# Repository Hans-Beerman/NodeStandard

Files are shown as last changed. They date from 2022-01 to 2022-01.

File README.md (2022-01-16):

**NodeStandard**

NodeStandard is the base for different nodes, used at the MakerSpace Leiden, to control different pieces of equipment. This repository has the following subdirs:

- **Drawings:**

- **Gerber_Files:**

This directory contains the Gerber files for production of the print. In this directory are the separate files and a *.ZIP file containing all these files. For ordering the printed circuit board, for example from JLCPCB, you only need to upload the ZIP file

Schematic of the wiring between the different modules used

- **KiCad\_files:**

The design of the PCB for the Node/Controller. De PCB in this design is not meant to be used for a real PCB. It is used as guideline for a handmade PCB

- **Photos:**

Some photos of the Node made.

- **PlatformIO\_Files:**

The source code for the Node and the display used. For the development of this software PlatformIO is used. PlatformIO is an Extension on Visual Studio Code.

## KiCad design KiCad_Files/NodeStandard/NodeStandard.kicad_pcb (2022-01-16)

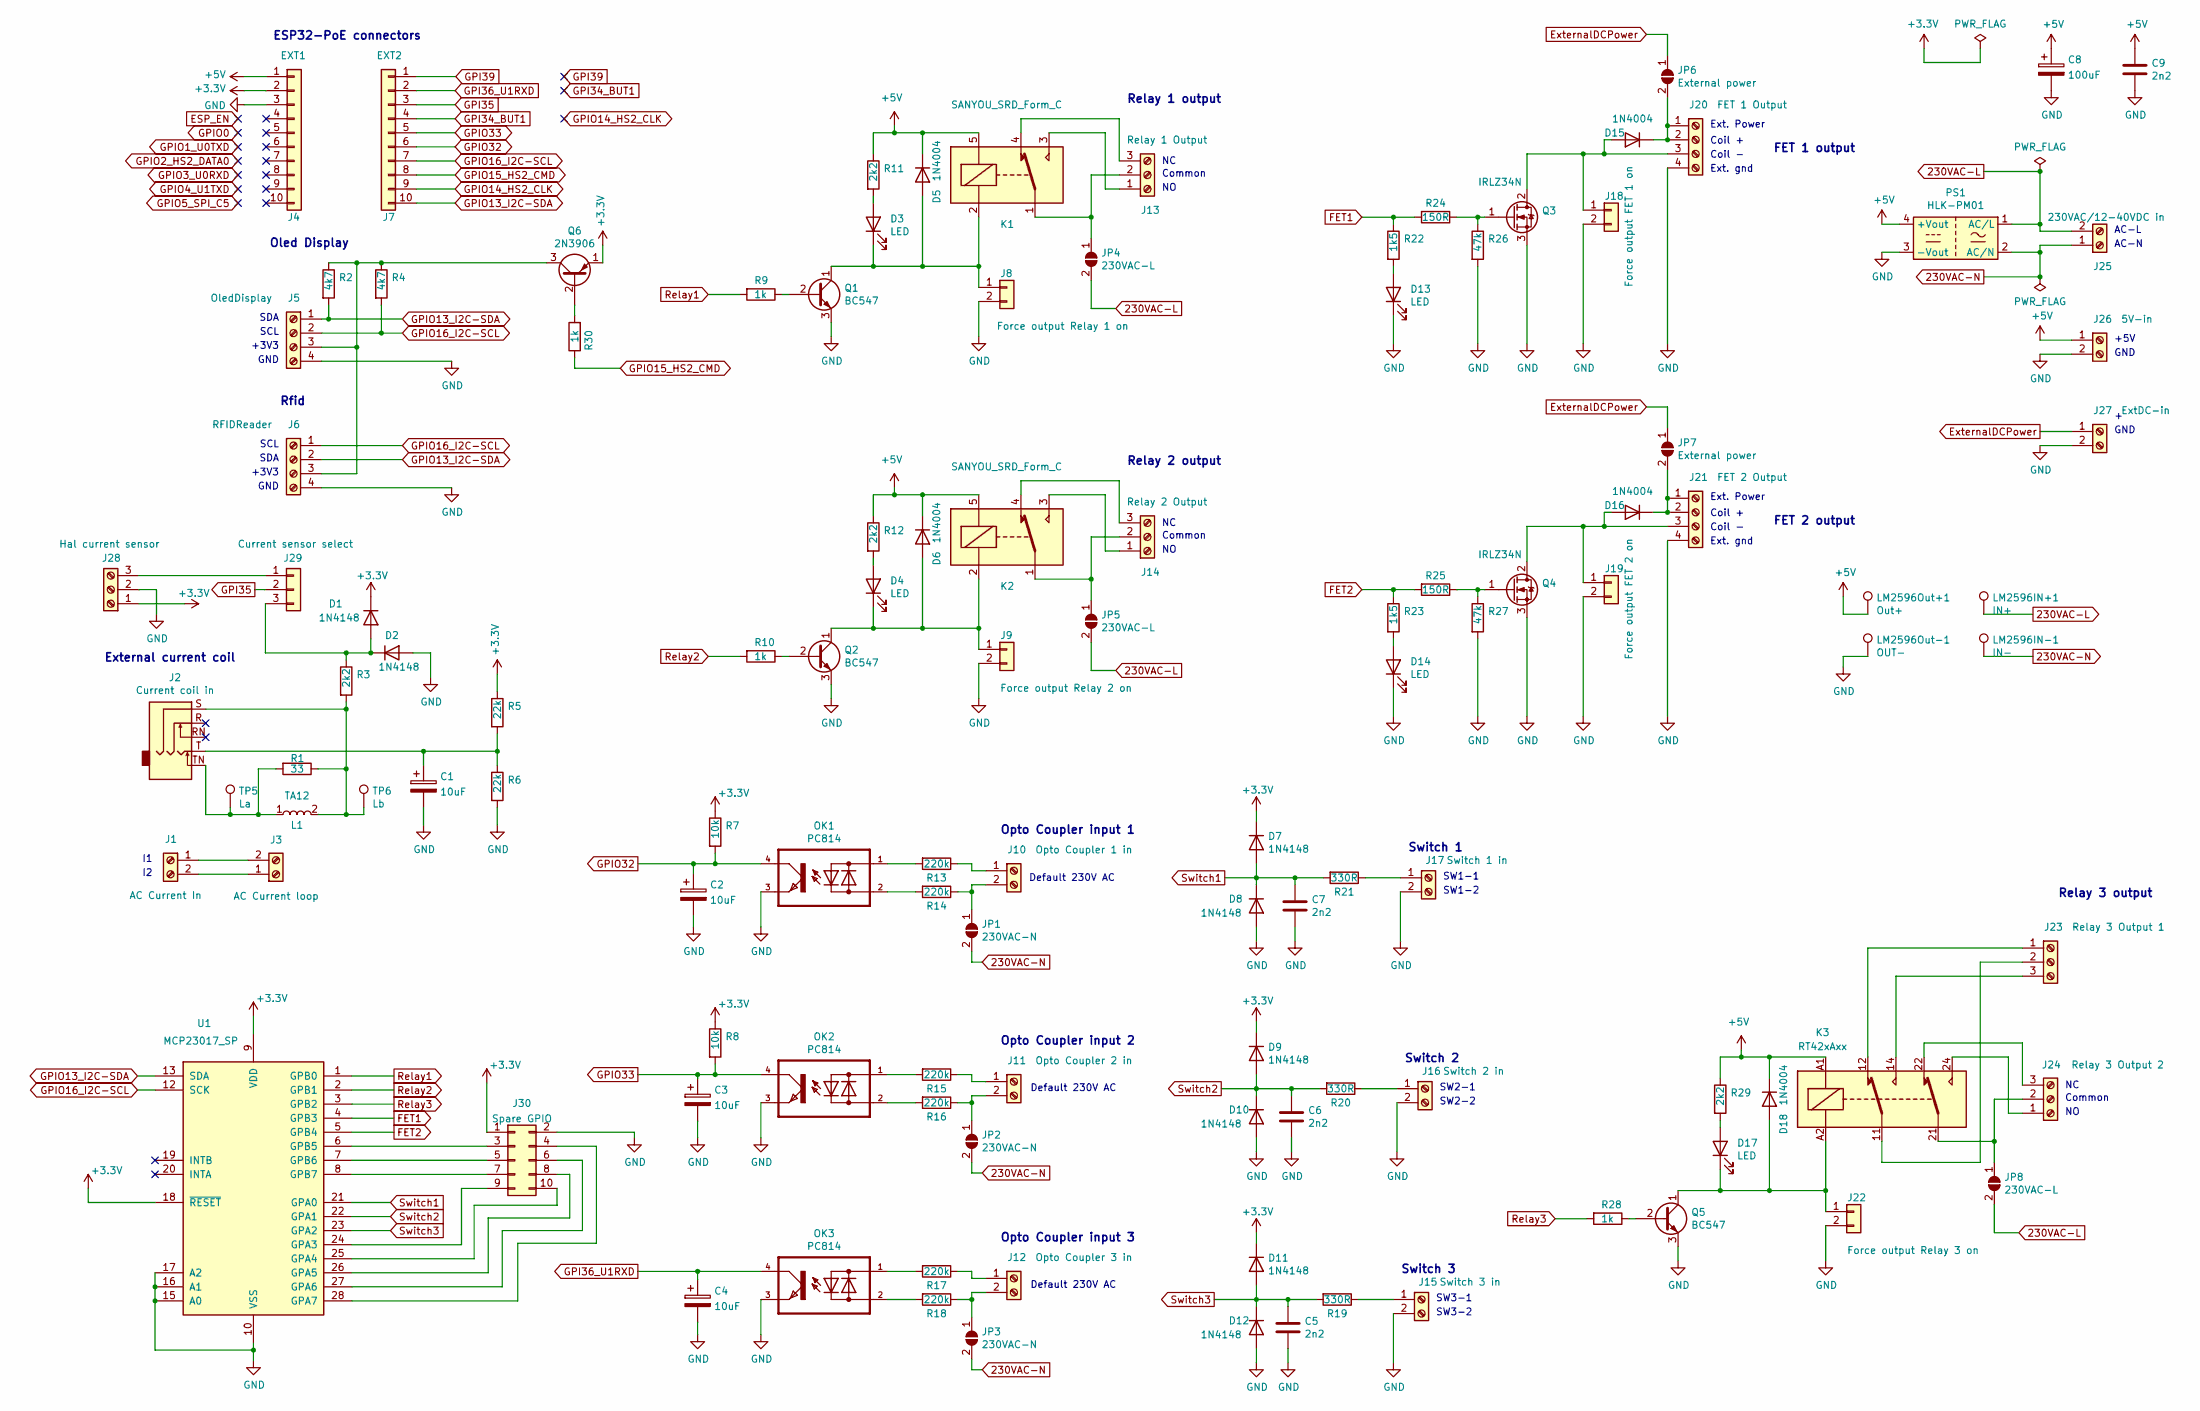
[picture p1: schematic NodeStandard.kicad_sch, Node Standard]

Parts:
C1, C2, C3, C4: 10uF; CP_Radial_D6.3mm_P2.50mm
C5, C6, C7, C9: 2n2; C_Disc_D5.1mm_W3.2mm_P5.00mm
C8: 100uF; CP_Radial_D6.3mm_P2.50mm
D1, D2, D7, D8, D9, D10, D11, D12: 1N4148; D_DO-35_SOD27_P7.62mm_Horizontal
D3, D4, D13, D14, D17: LED; LED_D3.0mm
D5, D6, D15, D16, D18: 1N4004; D_DO-41_SOD81_P10.16mm_Horizontal
J1: AC Current In; PhoenixContact_MSTB_2,5_2-GF-5,08_1x02_P5.08mm_Horizontal_T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
J2: Current coil in; Jack_3.5mm_CUI_FEMPM_Horizontal
J3: AC Current loop; TerminalBlock_Phoenix_MKDS-1,5-2-5.08_1x02_P5.08mm_Horizont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
J4: EXT1; PinSocket_1x10_P2.54mm_Vertical
J5: OledDisplay; TerminalBlock_Phoenix_MPT-0,5-4-2.54_1x04_P2.54mm_Horizontal
J6: RFIDReader; TerminalBlock_Phoenix_MPT-0,5-4-2.54_1x04_P2.54mm_Horizontal
J7: EXT2; PinSocket_1x10_P2.54mm_Vertical
J8: Force output Relay 1 on; PinHeader_1x02_P2.54mm_Vertical
J9: Force output Relay 2 on; PinHeader_1x02_P2.54mm_Vertical
J10: Opto Coupler 1 in; PhoenixContact_MSTB_2,5_2-GF-5,08_1x02_P5.08mm_Horizontal_T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
J11: Opto Coupler 2 in; PhoenixContact_MSTB_2,5_2-GF-5,08_1x02_P5.08mm_Horizontal_T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
J12: Opto Coupler 3 in; PhoenixContact_MSTB_2,5_2-GF-5,08_1x02_P5.08mm_Horizontal_T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
J13: Relay 1 Output; PhoenixContact_MSTB_2,5_3-GF-5,08_1x03_P5.08mm_Horizontal_T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
J14: Relay 2 Output; PhoenixContact_MSTB_2,5_3-GF-5,08_1x03_P5.08mm_Horizontal_T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
J15: Switch 3 in; TerminalBlock_Phoenix_MPT-0,5-2-2.54_1x02_P2.54mm_Horizontal
J16: Switch 2 in; TerminalBlock_Phoenix_MPT-0,5-2-2.54_1x02_P2.54mm_Horizontal
J17: Switch 1 in; TerminalBlock_Phoenix_MPT-0,5-2-2.54_1x02_P2.54mm_Horizontal
J18: Force output FET 1 on; PinHeader_1x02_P2.54mm_Vertical
J19: Force output FET 2 on; PinHeader_1x02_P2.54mm_Vertical
J20: FET 1 Output; PhoenixContact_MSTB_2,5_4-GF-5,08_1x04_P5.08mm_Horizontal_T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
J21: FET 2 Output; PhoenixContact_MSTB_2,5_4-GF-5,08_1x04_P5.08mm_Horizontal_T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
J22: Force output Relay 3 on; PinHeader_1x02_P2.54mm_Vertical
J23: Relay 3 Output 1; PhoenixContact_MSTB_2,5_3-GF-5,08_1x03_P5.08mm_Horizontal_T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
J24: Relay 3 Output 2; PhoenixContact_MSTB_2,5_3-GF-5,08_1x03_P5.08mm_Horizontal_T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
J25: 230VAC/12-40VDC in; PhoenixContact_MSTB_2,5_2-GF-5,08_1x02_P5.08mm_Horizontal_T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
J26: 5V-in; PhoenixContact_MSTB_2,5_2-GF-5,08_1x02_P5.08mm_Horizontal_T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
J27: ExtDC-in; PhoenixContact_MSTB_2,5_2-GF-5,08_1x02_P5.08mm_Horizontal_T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
J28: Hal current sensor; TerminalBlock_Phoenix_MPT-0,5-3-2.54_1x03_P2.54mm_Horizontal
J29: Current sensor select; PinHeader_1x03_P2.54mm_Vertical
J30: Spare GPIO; PinHeader_2x05_P2.54mm_Vertical
JP1, JP2, JP3: 230VAC-N; SolderJumper-2_P3mm_Open_RoundedPad
JP4, JP5, JP8: 230VAC-L; SolderJumper-2_P3mm_Open_RoundedPad
JP6, JP7: External power; SolderJumper-2_P1.3mm_Open_RoundedPad1.0x1.5mm
K1, K2: SANYOU_SRD_Form_C; Relay_SPDT_SANYOU_SRD_Series_Form_C
K3: RT42xAxx; Relay_DPDT_Schrack-RT2-FormC_RM5mm
L1: TA12; TA12-100
LM2596IN+1: IN+; TestPoint_THTPad_2.0x2.0mm_Drill1.0mm
LM2596IN-1: IN-; TestPoint_THTPad_2.0x2.0mm_Drill1.0mm
LM2596Out+1: Out+; TestPoint_THTPad_2.0x2.0mm_Drill1.0mm
LM2596Out-1: OUT-; TestPoint_THTPad_2.0x2.0mm_Drill1.0mm
OK1, OK2, OK3: PC814; DIP-4_W7.62mm
PS1: HLK-PM01; Converter_ACDC_HiLink_HLK-PMxx
Q1, Q2, Q5: BC547; TO-92_Inline
Q3, Q4: IRLZ34N; TO-220-3_Vertical
Q6: 2N3906; TO-92_Inline
R1: 33; R_Axial_DIN0207_L6.3mm_D2.5mm_P7.62mm_Horizontal
R2, R4: 4k7; R_Axial_DIN0207_L6.3mm_D2.5mm_P7.62mm_Horizontal
R3, R11, R12, R29: 2k2; R_Axial_DIN0207_L6.3mm_D2.5mm_P7.62mm_Horizontal
R5, R6: 22k; R_Axial_DIN0207_L6.3mm_D2.5mm_P7.62mm_Horizontal
R7, R8: 10k; R_Axial_DIN0207_L6.3mm_D2.5mm_P7.62mm_Horizontal
R9, R10, R28, R30: 1k; R_Axial_DIN0207_L6.3mm_D2.5mm_P7.62mm_Horizontal
R13, R14, R15, R16, R17, R18: 220k; R_Axial_DIN0516_L15.5mm_D5.0mm_P20.32mm_Horizontal
R19, R20, R21: 330R; R_Axial_DIN0207_L6.3mm_D2.5mm_P7.62mm_Horizontal
R22, R23: 1k5; R_Axial_DIN0207_L6.3mm_D2.5mm_P7.62mm_Horizontal
R24, R25: 150R; R_Axial_DIN0207_L6.3mm_D2.5mm_P7.62mm_Horizontal
R26, R27: 47k; R_Axial_DIN0207_L6.3mm_D2.5mm_P7.62mm_Horizontal
TP5: La; TestPoint_THTPad_2.5x2.5mm_Drill1.2mm
TP6: Lb; TestPoint_THTPad_2.5x2.5mm_Drill1.2mm
U1: MCP23017_SP; DIP-28_W7.62mm

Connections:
230VAC-L: J25.2, JP4.2 (B), JP5.2 (B), JP8.2 (B), LM2596IN+1.1, PS1.1 (AC/L)
230VAC-N: J25.1, JP1.2 (B), JP2.2 (B), JP3.2 (B), LM2596IN-1.1, PS1.2 (AC/N)
+3V3: D1.1 (K), D7.1 (K), D9.1 (K), D11.1 (K), J4.2, J28.1, J30.1, Q6.1 (E), R5.1, R7.1, R8.1, U1.9 (VDD), U1.18 (~RESET)
+5V: C8.1, C9.1, D5.1 (K), D6.1 (K), D18.1 (K), J4.1, J26.1, K1.5, K2.5, K3.A1, LM2596Out+1.1, PS1.4 (+Vout), R11.1, R12.1, R29.1
ExternalDCPower: J27.1, JP6.1 (A), JP7.1 (A)
FET1: R22.1, R24.2, U1.4 (GPB3)
FET2: R23.1, R25.2, U1.5 (GPB4)
GND: C1.2, C2.2, C3.2, C4.2, C5.2, C6.2, C7.2, C8.2, C9.2, D2.2 (A), D8.2 (A), D10.2 (A), D12.2 (A), D13.1 (K), D14.1 (K), J4.3, J5.4, J6.4, J8.2, J9.2, J15.2, J16.2, J17.2, J18.2, J19.2, J20.4, J21.4, J22.2, J26.2, J27.2, J28.2, J30.2, LM2596Out-1.1, OK1.3 (E), OK2.3 (E), OK3.3 (E), PS1.3 (-Vout), Q1.3 (E), Q2.3 (E), Q3.3 (S), Q4.3 (S), Q5.3 (E), R6.2, R26.2, R27.2, U1.10 (VSS), U1.15 (A0), U1.16 (A1), U1.17 (A2)
GPI34_BUT1: J7.4
GPI35: J7.3, J29.2
GPI36_U1RXD: C4.1, J7.2, OK3.4 (C)
GPI39: J7.1
GPIO13_I2C-SDA: J5.1, J6.2, J7.10, R2.2, U1.13 (SDA)
GPIO14_HS2_CLK: J7.9
GPIO15_HS2_CMD: J7.8, R30.1
GPIO16_I2C-SCL: J5.2, J6.1, J7.7, R4.2, U1.12 (SCK)
GPIO32: C2.1, J7.6, OK1.4 (C), R7.2
GPIO33: C3.1, J7.5, OK2.4 (C), R8.2
unnamed: C1.1, J2.T, R5.2, R6.1
unnamed: D1.2 (A), D2.1 (K), J29.3, R3.1
unnamed: D3.1 (K), D5.2 (A), J8.1, K1.2, Q1.1 (C)
unnamed: D3.2 (A), R11.2
unnamed: D4.1 (K), D6.2 (A), J9.1, K2.2, Q2.1 (C)
unnamed: D4.2 (A), R12.2
unnamed: D13.2 (A), R22.2
unnamed: D14.2 (A), R23.2
unnamed: D15.1 (K), J20.1, J20.2, JP6.2 (B)
unnamed: D15.2 (A), J18.1, J20.3, Q3.2 (D)
unnamed: D16.1 (K), J21.1, J21.2, JP7.2 (B)
unnamed: D16.2 (A), J19.1, J21.3, Q4.2 (D)
unnamed: D17.1 (K), D18.2 (A), J22.1, K3.A2, Q5.1 (C)
unnamed: D17.2 (A), R29.2
unnamed: J1.1, J3.2
unnamed: J1.2, J3.1
unnamed: J2.S, L1.2, R1.1, R3.2, TP6.1
unnamed: J2.TN, L1.1, R1.2, TP5.1
unnamed: J5.3, J6.3, Q6.3 (C), R2.1, R4.1
unnamed: J10.1, R13.1
unnamed: J10.2, JP1.1 (A), R14.1
unnamed: J11.1, R15.1
unnamed: J11.2, JP2.1 (A), R16.1
unnamed: J12.1, R17.1
unnamed: J12.2, JP3.1 (A), R18.1
unnamed: J13.1, K1.3
unnamed: J13.2, JP4.1 (A), K1.1
unnamed: J13.3, K1.4
unnamed: J14.1, K2.3
unnamed: J14.2, JP5.1 (A), K2.1
unnamed: J14.3, K2.4
unnamed: J15.1, R19.1
unnamed: J16.1, R20.1
unnamed: J17.1, R21.1
unnamed: J23.1, K3.12
unnamed: J23.2, K3.11
unnamed: J23.3, K3.14
unnamed: J24.1, K3.24
unnamed: J24.2, JP8.1 (A), K3.21
unnamed: J24.3, K3.22
unnamed: J28.3, J29.1
unnamed: J30.3, U1.6 (GPB5)
unnamed: J30.4, U1.28 (GPA7)
unnamed: J30.5, U1.7 (GPB6)
unnamed: J30.6, U1.27 (GPA6)
unnamed: J30.7, U1.8 (GPB7)
unnamed: J30.8, U1.26 (GPA5)
unnamed: J30.9, U1.24 (GPA3)
unnamed: J30.10, U1.25 (GPA4)
unnamed: OK1.1 (AC1), R13.2
unnamed: OK1.2 (AC2), R14.2
unnamed: OK2.1 (AC1), R15.2
unnamed: OK2.2 (AC2), R16.2
unnamed: OK3.1 (AC1), R17.2
unnamed: OK3.2 (AC2), R18.2
unnamed: Q1.2 (B), R9.1
unnamed: Q2.2 (B), R10.1
unnamed: Q3.1 (G), R24.1, R26.1
unnamed: Q4.1 (G), R25.1, R27.1
unnamed: Q5.2 (B), R28.1
unnamed: Q6.2 (B), R30.2
Relay1: R9.2, U1.1 (GPB0)
Relay2: R10.2, U1.2 (GPB1)
Relay3: R28.2, U1.3 (GPB2)
Switch1: C7.1, D7.2 (A), D8.1 (K), R21.2, U1.21 (GPA0)
Switch2: C6.1, D9.2 (A), D10.1 (K), R20.2, U1.22 (GPA1)
Switch3: C5.1, D11.2 (A), D12.1 (K), R19.2, U1.23 (GPA2)

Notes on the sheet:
SDA
GND
+3V3
Ext. gnd
SW3-2
Switch 3
+5V
Rfid
SCL
SW2-1
ESP32-PoE connectors
Common
AC-L
Default 230V AC
Ext. Power
Coil +
Switch 2
Relay 2 output
SW2-2
External current coil
SW1-1
Coil -
Switch 1
SW1-2
Relay 3 output
FET 1 output
Oled Display
Opto Coupler input 2
Opto Coupler input 1
AC-N
Relay 1 output
Opto Coupler input 3
FET 2 output
SW3-1

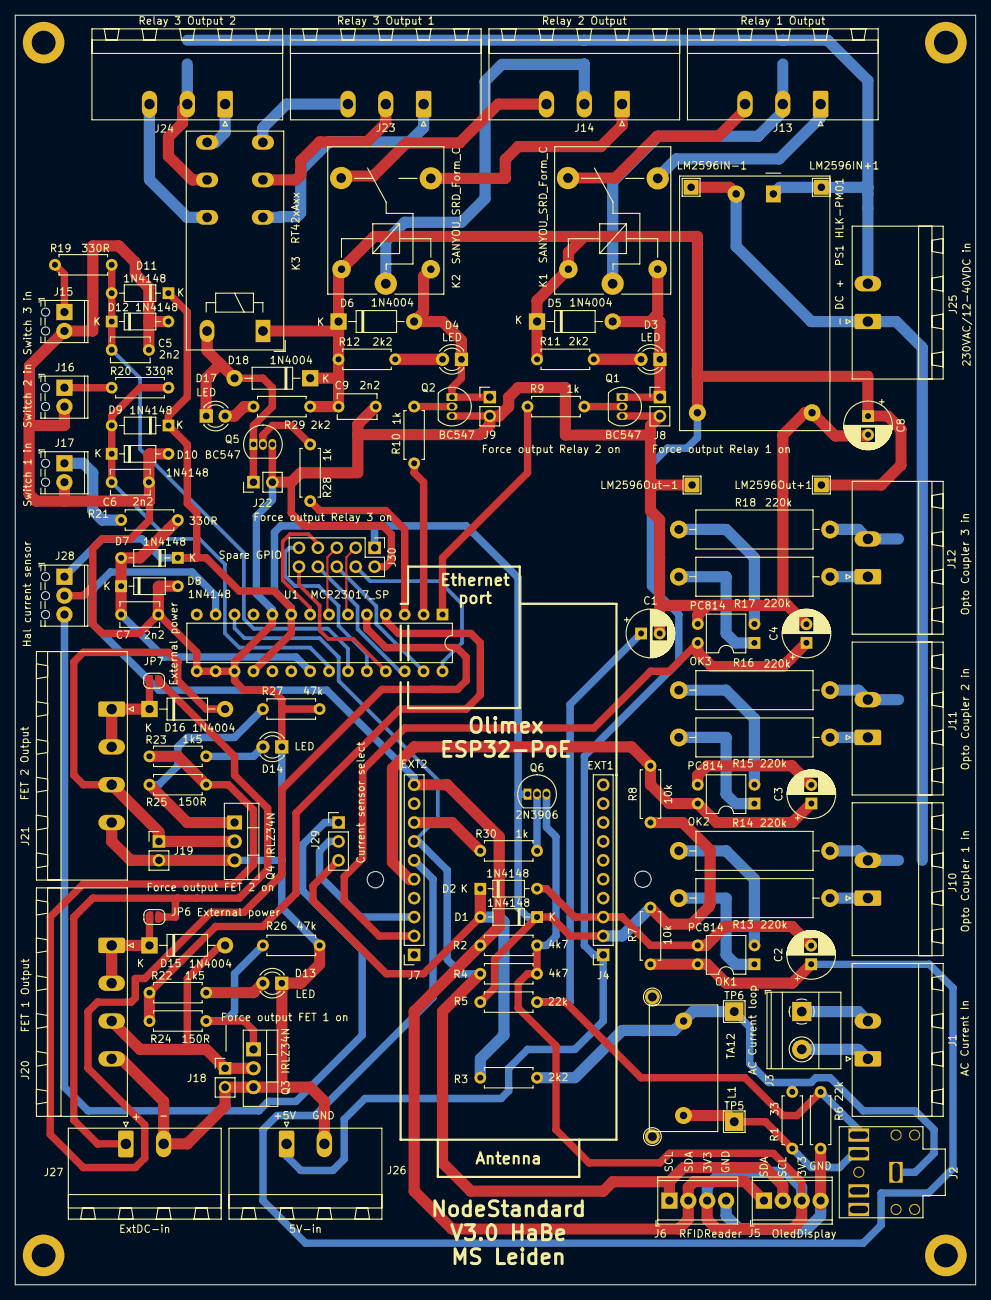
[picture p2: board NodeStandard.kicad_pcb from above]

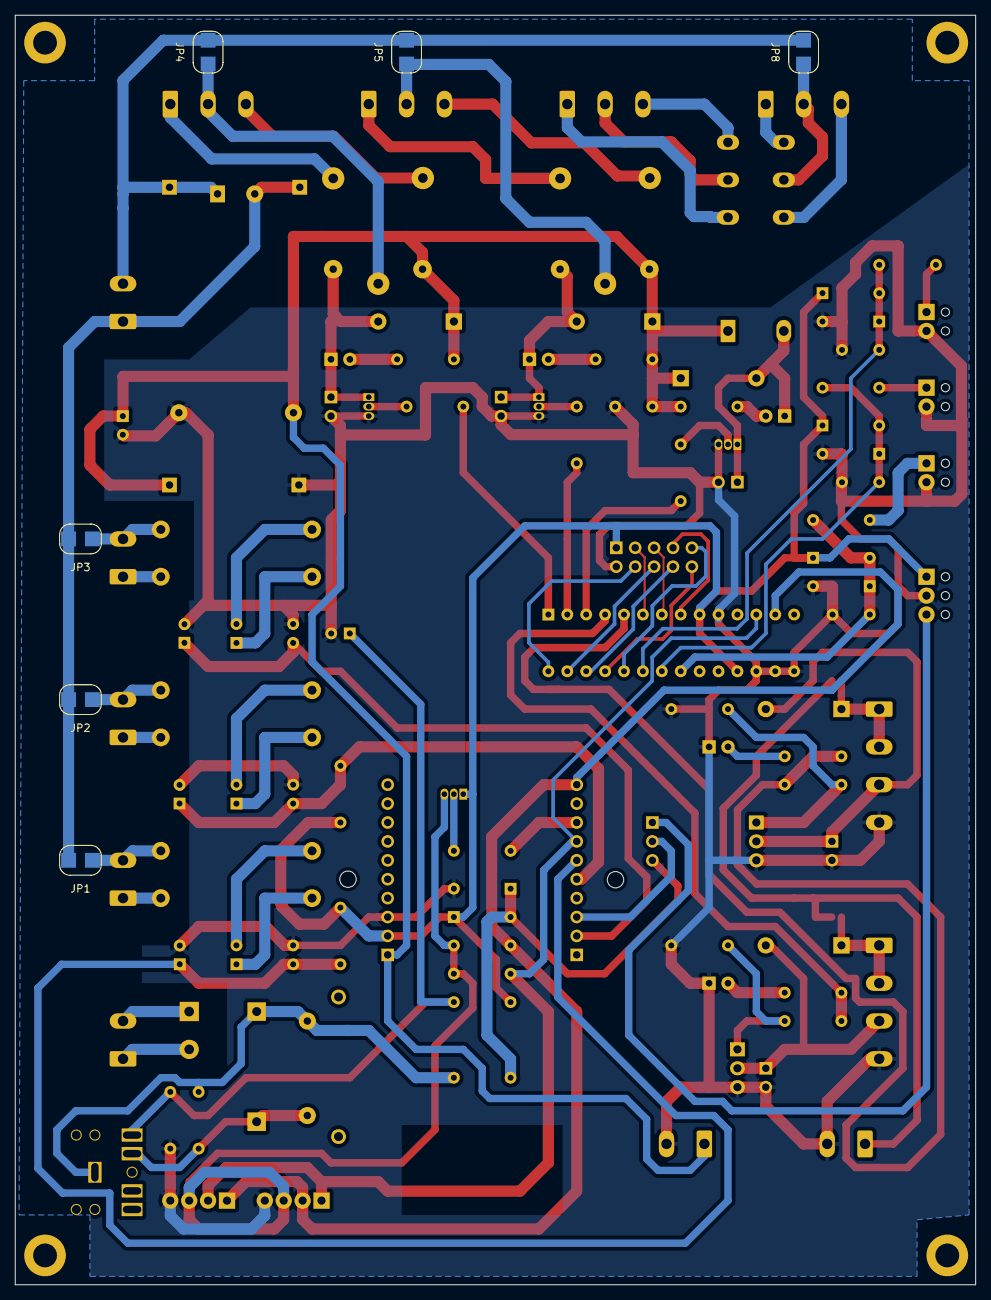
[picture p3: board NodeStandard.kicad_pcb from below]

Board: 2 copper layers, 129.0 x 170.6 mm, 116 parts (6 on the bottom side), 82 nets.

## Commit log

2020-11-12 First design
    [NodeStandard.kicad_pcb, NodeStandard.sch]
2020-11-24 V0.3.0.0 Work in progress, layout of components on PCB added
    [NodeStandard.sch]
2020-11-24 V0.4 Work in progress, added some footprints with 3D models
    [NodeStandard.kicad_pcb, NodeStandard.sch]
2020-12-04 V0.5 Work in progress, first version PCB design, no silk screen yet
    [NodeStandard.kicad_pcb, NodeStandard.sch]
2020-12-13 V0.6 Silk screen added, ready for first trial with real print
    [NodeStandard.kicad_pcb, NodeStandard.sch]
2021-01-05 V0.7 a few changes needed for the production of the PCB
    [NodeStandard.kicad_pcb, NodeStandard.sch]
2021-01-06 V0.8 moved a mounting hole and generated Gerber files
    [NodeStandard-B_Cu.gbr, NodeStandard-B_Mask.gbr, NodeStandard-B_Paste.gbr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]
2021-02-18 Version 0.9: 2 typo's in silkscreen labels corrected
    [NodeStandard-B_Cu.gbr, NodeStandard-B_Mask.gbr, NodeStandard-B_Paste.gbr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]
2021-02-20 Version 0.9 corrected typo's on silk screen added ESP32 model on silk screen + added 2 holes to fixate ESP32 with tie wrap or so
    [NodeStandard-B_Cu.gbr, NodeStandard-B_Mask.gbr, NodeStandard-B_Paste.gbr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]
2021-04-23 V0.0.9.0 added a number of improvements
    [NodeStandard-B_Cu.gbr, NodeStandard-B_Mask.gbr, NodeStandard-B_Paste.gbr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]
2022-01-16 Third (fysical) version of the PCB for this node. Added a header to provide access to some free (currently not used GPIO ports), also made the holes for the coil a little bit wider
    [NodeStandard-B_Cu.gbr, NodeStandard-B_Mask.gbr, NodeStandard-B_Paste.gbr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]
